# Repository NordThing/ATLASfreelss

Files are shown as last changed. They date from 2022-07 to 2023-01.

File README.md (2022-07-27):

# REWORK of ATLAS 3D scanner

ATLAS 3D scanner files - both for hardware and software and 3d printing files collected on one place.
Will make total rework of the ATLAS 3D scanner.

A link for assembling https://youtu.be/TEsBM5ACriQ 
and one more https://www.youtube.com/watch?v=awtLSCLJ3qs

Calibration video https://youtu.be/vvfXvUgtoUg

# FreeLSS

FreeLSS is a laser scanning program for the Raspberry Pi. It allows a Raspberry Pi to function as the core to a complete turn table laser scanning system.

### COMPILE

These instructions assume you are running the latest version of Raspbian.  Other distros will likely require changes.

First, update the firmware to the latest version and reboot.
```
$ sudo apt-get update
$ sudo apt-get upgrade
```

Install the dependencies that are managed by the package manager.
```
$ sudo apt-get install libpng-dev libjpeg-dev git-core gcc build-essential unzip sqlite3 libsqlite3-dev libmicrohttpd-dev libcurl4-openssl-dev libiw-dev libssl-dev wiringpi 
```

Download and build FreeLSS
```
$ git clone https://github.com/hairu/freelss
$ cd freelss
$ make
```
### Running FreeLSS
FreeLSS must be ran as root (or another user with access to the hardware pins).  The interface for FreeLSS is web based and by default runs on port 80.  When running, access it by navigating to http://localhost/ from the Raspberry Pi itself. Or access it from another machine on the network by the Raspberry Pi's IP or hostname.  For Example: http://raspberrypi/

The following command starts FreeLSS.
```
$ cd src
$ sudo ./freelss
```

The following command automatically starts FreeLSS everytime the Raspberry Pi is powered on.
```
$ make startup
```

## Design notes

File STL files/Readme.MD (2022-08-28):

# STL files for 3d printing

Printing times for the files here: 
1. Printing parts nr 1-5 for the camera - estimated time 49min, printing time 100mm/sec 30% infill 1h 25min 13 sec
   - camera_arm
   - camera_bracket
   - camera_case_back
   - camera_case_front
   - camera_shaft
2. Printing part nr 6 - frame_connector x 6 - estimated time 2h 29 min, printing time 100mm/sec 30% infill 4h 8min 19sec
3. Printing part nr 7 - frame_section_2 x 2 - estimated time 1h 31min, printing time 100mm/sec 30% infill 2h 21min 36sec
4. Printing parts 8-9 - estimated time 1h 45 min, printing time 100mm/sec 30% infill 2h 54min 42sec
   - left_laser_arm
   - right_laser_arm 
5. Printing parts 10-11 - estimated time xh xxmin, printing time 100mm/sec 30% infill xh xxmin xxsec
   - left_frame_section_3
   - right_frame_section_3
6. Printing parts 12-14 - estimated time 1h 20min, printing time 100mm/sec 30% infill 2h 13min 10sec
   - left_laser_holder
   - right_laser_holder
   - rpi_cable_carrier x 4
   - cross_bar x 5
7. Printing parts 16-17
   - camera_tower
   - camera_tower_front_plate
9.    

# STL files for 3d printing - probably a better print order

1. Printing the frame_connector x 6 
2. Printing the frame_section_2 x 4
3. Printing cross_bar x5
4. Print the right raspberry pi case for your purpose
5. Print the camera_tower 

Summary
These are the printable models for the ATLAS 3D turntable laser scanner by Murobo. ATLAS 3D is a turntable 3D laser scanner based on the Raspberry Pi. It runs the open source FreeLSS http://www.freelss.org laser scanning software available on Github https://github.com/hairu/freelss/. ATLAS 3D is a successful Kickstarter that is now available to the public.

The following models are required to build ATLAS 3D:

1. camera_arm.stl, x 1
2. camera_bracket.stl, x 1
3. camera_case_back.stl, x 1
4. camera_case_front.stl, x 1
5. camera_shaft.stl, x 1
6. frame_connector.stl, x 6
7. frame_section_2.stl, x 4
8. left_laser_arm.stl, x 1
9. right_laser_arm.stl, x 1
10. left_frame_section 3.stl, x 1
11. right_frame_section 3.stl, x 1
12. left_laser_holder.stl, x 1
13. right_laser_holder.stl, x 1
14. rpi_cable_carrier.stl, x 4
15. crossbar.stl, x 5
16. camera_tower.stl, x 1
17. camera_tower_front_plate.stl, x 1
18. table_coupler.stl, x 1
19. 
    - calibration_item.stl or 
    - checkerboard_calibration_item.stl, x 1
20. The calibrationPattern.pdf in the folder /calibration/ file needs to be printed and glued onto the checkerboard_calibration_item.stl model if you want to use the checkerboard auto-calibration.

Raspberry Pi 2 and Raspberry Pi 1 Model B+ users need to print the below two models.

1. rpi_case_bplus_lower.stl
2. rpi_case_bplus_upper.stl

Raspberry Pi 1 Model B users need to print the below two models.

1. rpi_case_b_lower.stl
2. rpi_case_b_upper.stl

Only one of the following turntables needs to be printed.

1. turn_table_d4.stl, 4" turntable
2. turn_table_d5p5.stl, 5.5" turntable
3. turn_table_d7p5.stl, 7.5" turntable

The following models are either optional or alternatives models.

1. camera_bracket_no_support.stl
2. left_camera_tower.stl
3. right_camera_tower.stl

The following models are only for the acrylic version of the enclosure.
1. left_laser_hinge.stl
2. left_laser_hinge_holder.stl
3. right_laser_hinge.stl
4. right_laser_hinge_holder.stl

Assembly Video: https://www.youtube.com/watch?v=awtLSCLJ3qs
Printable Instructions: http://www.soliforum.com/topic/13217/atlas-3d-scanner-instructions/

Another remix 
https://www.thingiverse.com/thing:754003

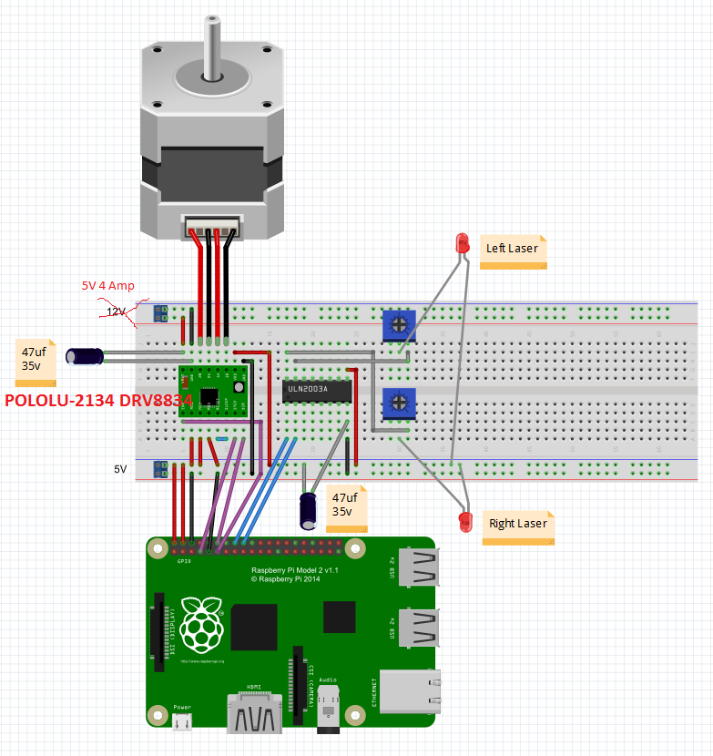
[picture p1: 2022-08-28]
electronic design/VDFLDOP.png

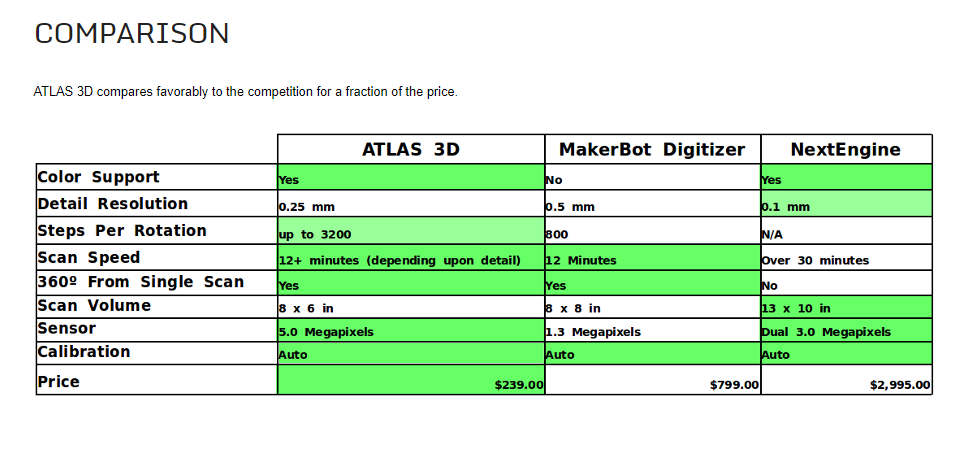
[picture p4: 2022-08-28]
comparison.PNG

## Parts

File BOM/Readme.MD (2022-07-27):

# Bill of materials

Board
1. 1 x Pololu A4988 stepper driver
2. 1 x ULN2003A
3. 2 x 47UF 35v low ESR
4. 2 x 10uf 5v capacitor
5. 2 x 100 ohm variable resistors

Electronic
1. 1 x Raspberry Pi 2
2. 1 x Power adapter for the Pi
3. 1 x Pi WiFi dongle
4. 1 x Official Pi camera 5Mp (version 1)
5. 2 x 3.3V line laser
6. 1 x Nema17 stepper motor

Hardware
1. 43 x M3x10mm flat head screws (Bag A)
2. 73 x M3 hex nuts (Bag B)
3. 34 x M3 washers (Bag C)
4. 31 x M3 14mm round head or socket cap screws (Bag D)
5. 4 x M2.5x10 flat head screws (Bag E)
6. 4 x M2.5 jam nuts (Bag F)
7. 4 x M3x20mm flat head screws (Bag G)
8. 4 x M2.5 washers (Bag H)

For the printed case's set of fasteners:
1. "Bag A" as referenced in the instructions is 43x M3x10mm screws.
2. "Bag B" is 73x M3 hex nuts
3. "Bag C" is 34 M3 washers
4. "Bag D" is 31 M3 socket cap screws
5. "Bag E" is 4x M2.5x10 screws
6. "Bag F" is 4x M2.5 jam nuts
7. "Bag G" is 4x M3x20mm screws
8. "Bag H" is 4x M2.5 washers

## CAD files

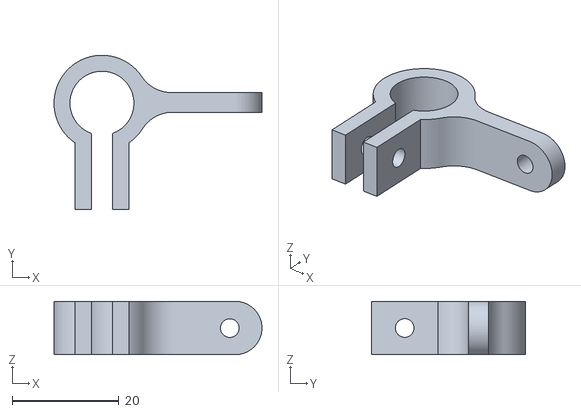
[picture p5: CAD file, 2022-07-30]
STL files/12mm_Laser_Holder_for_Atlas.stl
39.0 x 29.0 x 10.0

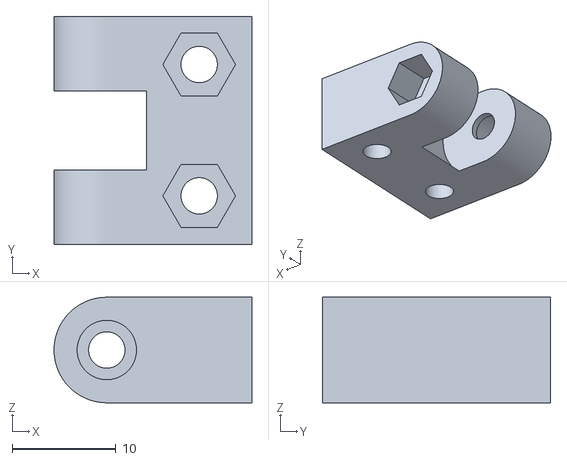
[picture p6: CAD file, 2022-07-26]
STL files/right_laser_hinge.stl
19.1 x 22.0 x 10.2

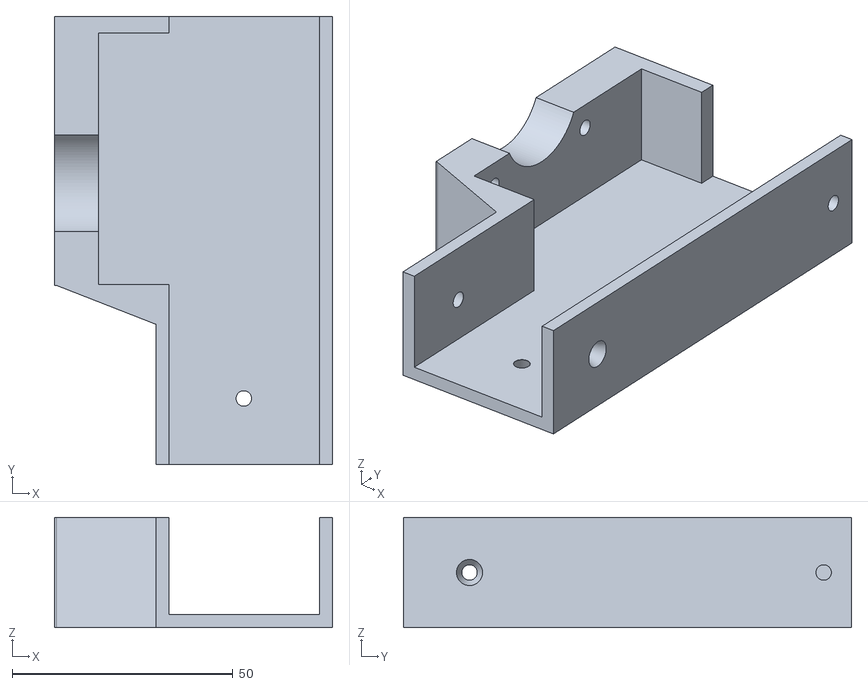
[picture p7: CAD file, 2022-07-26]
STL files/left_frame_section_3.stl
63.0 x 101.6 x 25.0

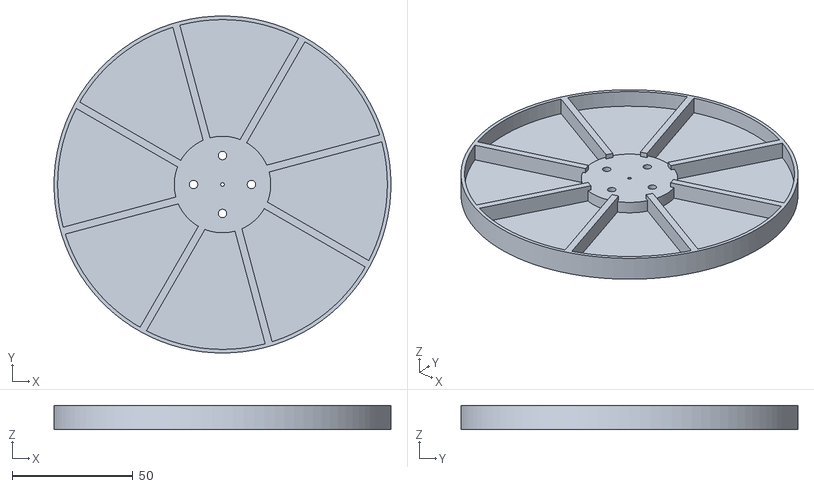
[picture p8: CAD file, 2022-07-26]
STL files/turn_table_d5p5.stl
139.7 x 139.7 x 10.0

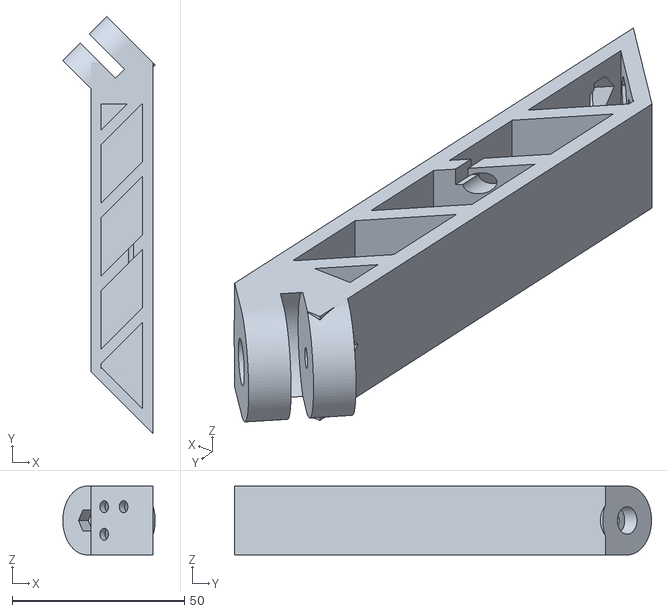
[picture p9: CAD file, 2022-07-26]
STL files/left_laser_arm.stl
26.9 x 121.2 x 20.0

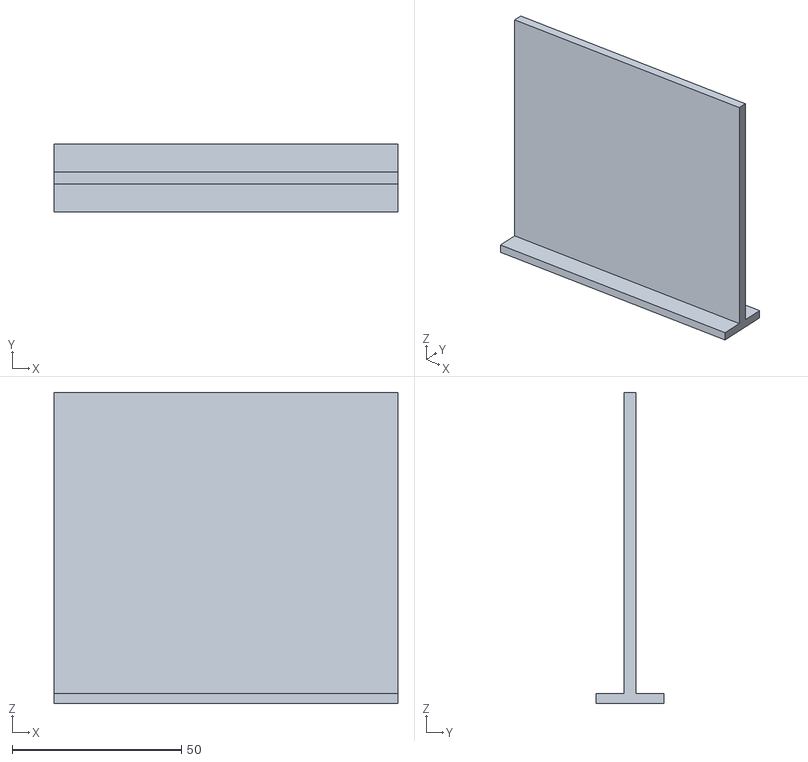
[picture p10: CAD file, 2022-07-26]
STL files/checkerboard_calibration_item.stl
101.6 x 20.0 x 91.9

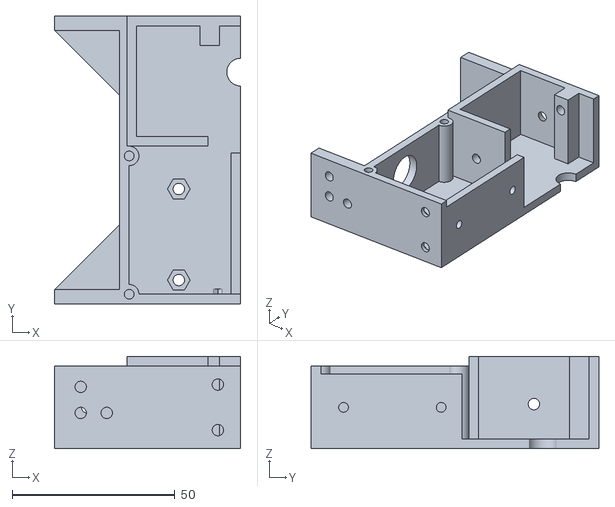
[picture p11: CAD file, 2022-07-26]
STL files/left_camera_tower.stl
57.2 x 88.5 x 28.4

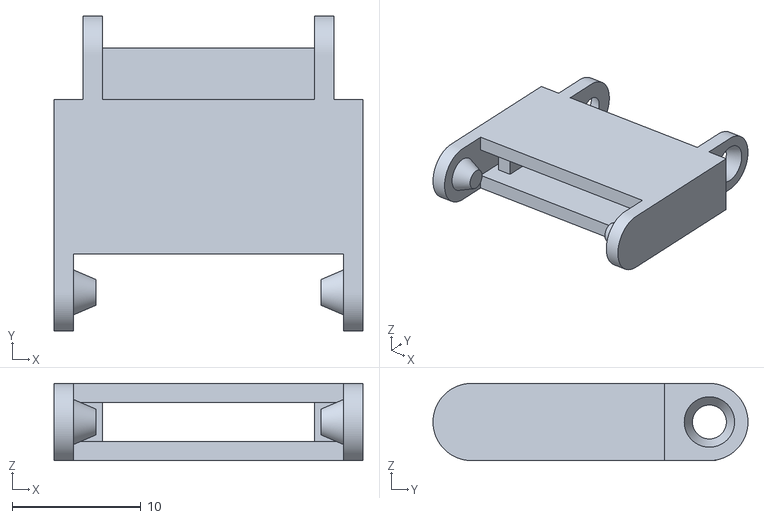
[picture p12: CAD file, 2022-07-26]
STL files/rpi_cable_carrier.stl
24.0 x 24.5 x 6.00

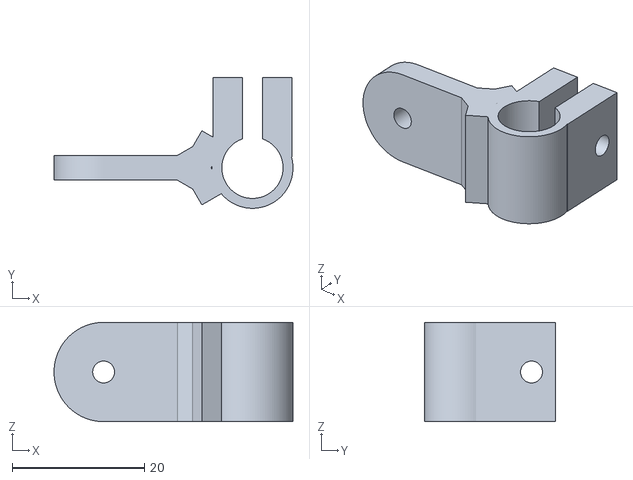
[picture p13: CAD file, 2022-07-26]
STL files/left_laser_holder.stl
36.1 x 19.8 x 15.0

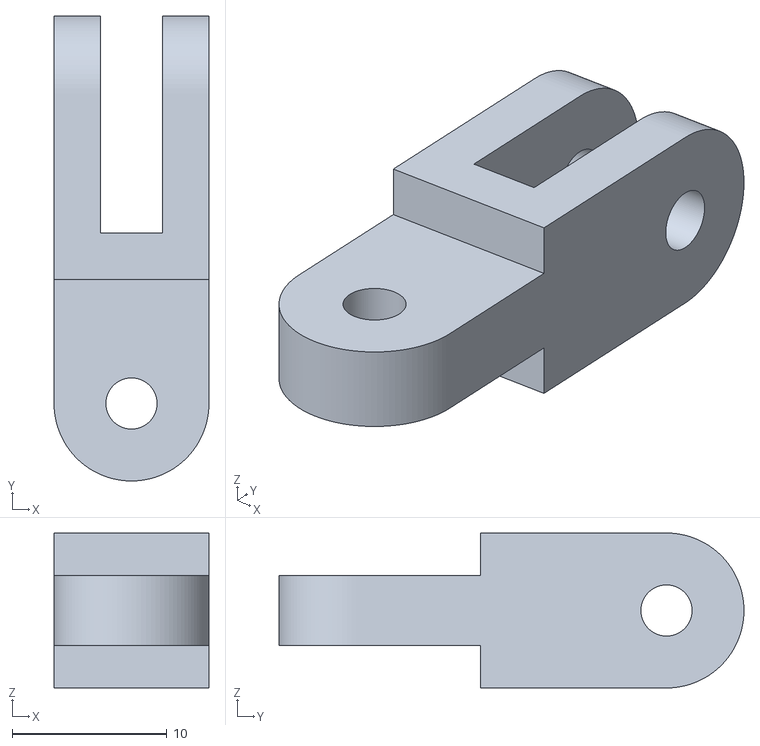
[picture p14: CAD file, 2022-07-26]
STL files/camera_bracket_no_support.stl
10.0 x 30.0 x 10.0

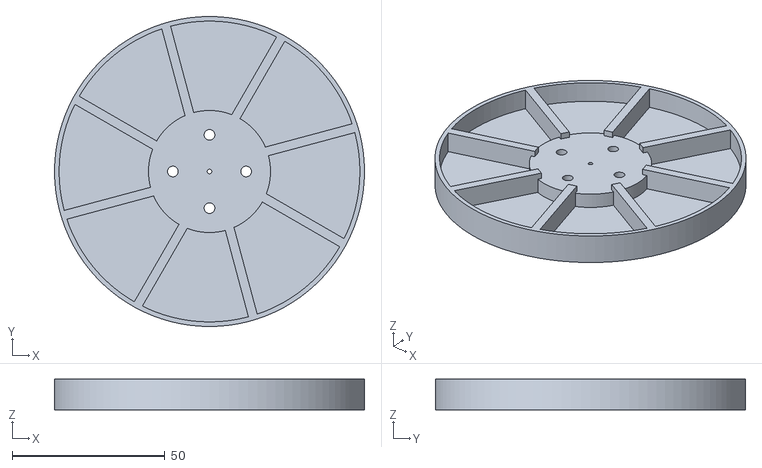
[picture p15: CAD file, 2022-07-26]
STL files/turn_table_d4.stl
101.6 x 101.6 x 10.0

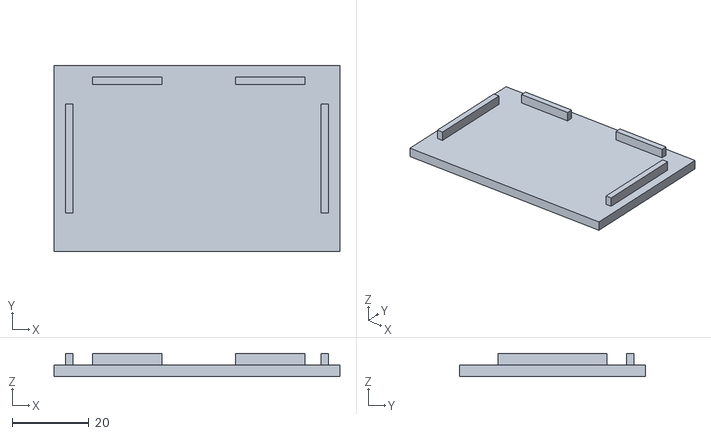
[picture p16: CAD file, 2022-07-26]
STL files/camera_tower_front_plate.stl
74.5 x 48.5 x 6.00

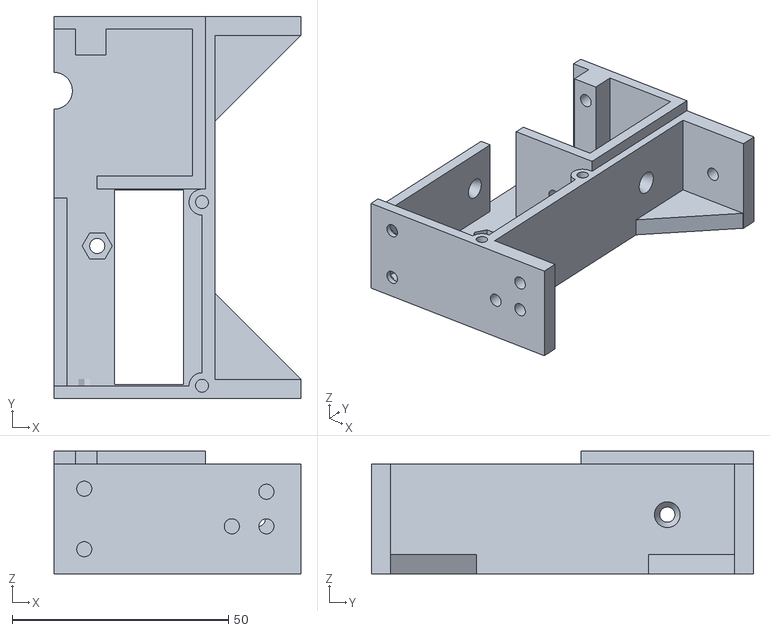
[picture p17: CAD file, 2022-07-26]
STL files/right_camera_tower.stl
57.1 x 88.5 x 28.4

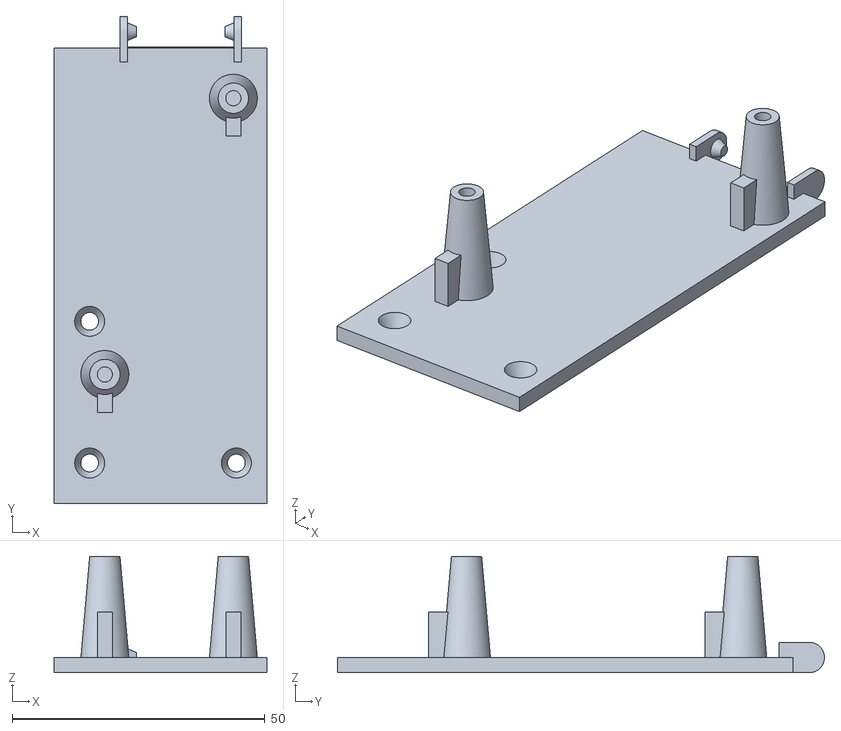
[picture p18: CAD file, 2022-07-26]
STL files/rpi_case_b_upper.stl
42.0 x 96.2 x 23.0

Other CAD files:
STL files/right_laser_holder.stl
STL files/left_laser_hinge.stl
STL files/camera_bracket.stl
STL files/camera_tower.stl
STL files/calibration_item.stl
STL files/camera_arm.stl
STL files/camera_case_back.stl
STL files/camera_case_front.stl
STL files/camera_shaft.stl
STL files/cross_bar.stl
STL files/frame_connector.stl
STL files/frame_section_2.stl
STL files/left_laser_hinge_holder.stl
STL files/right_frame_section_3.stl
STL files/right_laser_arm.stl
STL files/right_laser_hinge_holder.stl
STL files/rpi_case_b_lower.stl
STL files/rpi_case_bplus_lower.stl
STL files/rpi_case_bplus_upper.stl
STL files/table_coupler.stl
STL files/turn_table_d7p5.stl

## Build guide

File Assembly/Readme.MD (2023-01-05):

How to assemble the parts!

Where to start? 

Mount the FRAME
1. Mount all M3 nuts into all connectors first frame_connector.stl, each connector should have 6pcs M3 Nuts
2. Takae the frame-connector and connect to frame_section_2.stl with M3x10 mm screws. Screw in all three holes. 
3. The the next frame_section_2.stl and use with M3x10 screws. Screw in all three holes. 
4. Thake a new frame_connector.stl, eac connector should have 6 pcs m3 nuts. 
5. Attach the new frame_connector.stl with the frame_section_2 that is already there. 
6. Take left_frame_section_3.stl and connect it to the the new frame_section_2.stl with M3x10 in three screw holes. 
7. Attach a new frame_connector.stl on the opposite side. 
8. REPEAT EXACTLY THIS ONE MORE TIME - and you will have to identical sides 

Mount the Two frames together
1. Take cross_bar.stl and mount to one side with a M3 nuts and M3x10 screw 
2. Mount all 4x cross_bar.stl with M3 and M3x10 screws. 

Mount the motor
1. Take the motor and place it in the big hole with the axle at the center hole. 
2. Screw it with 4 screws - which size and with bricks. 

Mount the sides

Mount the camera-pole
1. Use the B nuts, c strings and D screws 
2. This is also questionable if we should use other screws for this part - i think the M3x10 screws will work for this part also. 

Mount the tower for laser 
1. Use the B nuts, c strings and D-screws. 
2. This is a real hazzle to mount the tower for the laser... needs improvement. 

Mount the laser-holder 
1. Put the mount for the laser-holder on the tower both left and right

Mount the camera holder on the camera-tower
1. camera_bracket.stl
2. camera_arm.stl

Mount the camera on the camera-arm 
1. 

1. Mount the Laser-pointer to the right mount. 12mm_Laser_Holder_for_Atlas.stl
2.

Mount the frame - 
Letter B - Hex M3 nuts 
Letter A - M3 x 10 mm

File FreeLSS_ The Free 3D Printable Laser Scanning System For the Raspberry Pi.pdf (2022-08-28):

## The Free 3D Printable Laser Scanning System

Get a Scanner Kit! (https://web.archive.org/web/20220226222454/https://www.kickstarter.com/projects/1545315380/atlas-3d-the-3d-scanner-you-print-and-build-yourse)

Get an ATLAS 3D scanner kit based on the FreeLSS software from the Murobo store. (https://web.archive.org/web/20220226222454/http://store.murobo.com/)

## About FreeLSS

FreeLSS is a free as in open source, open hardware, and open electronic design 3D printable turn table laser scanning platform based on the Raspberry Pi. (https://web.archive.org/web/20220226222454/http://www.raspberrypi.org/) It is written in C++ and licensed under the GPL. The scanning software runs self-contained on the Raspberry Pi without the need for a connected computer via USB. The user interface is completely web based and is exposed via libmicrohttpd (https://web.archive.org/web/20220226222454/http://www.gnu.org/software/libmicrohttpd/) on the Pi. Laser sensing is performed

The Wayback Machine - https://web.archive.org/web/20220226222454/http://www.freelss.org/

via the official 5 MP Raspberry Pi camera. The camera can be operated in either video or still mode. Video
mode camera access is provided by the | Raspicam (https://web.archive.org/web/20220226222454/http://www.uco.es/investiga/grupos/ava/node/40) library. Reference designs for the electronics to control the
lasers and turn table are available as | Fritzing (https://web.archive.org/web/20220226222454/http://fritzing.org/home/) files. Access to the GPIO pins are provided by | wiringPi. (https://web.archive.org/web/20220226222454/http://wiringpi.com/)

## Features

Fully 3D Printable
Point cloud export
Triangle mesh export
Assisted calibration
Support for dual laser lines (right and left)
Up to 6400 samples per table revolution (with reference electronics) 5 megapixel camera sensor
Support for camera Still mode and Video code
Configurable Image Processing Settings
Ability to generate images at different stages of the image processing pipeline for debugging Persistant storage of previous scans
Manual control of lasers and turn table
Flexible architecture

## Formats

FreeLSS can generate results in the following formats. PLY - Colored Point Cloud
XYZ - Comma Delimited 3D Point Cloud
STL - 3D Triangle Mesh

## Download

Download the source on | Github. (https://web.archive.org/web/20220226222454/http://github.com/hairu/freelss)
Download the printable hardware files from | Thingiverse. (https://web.archive.org/web/20220226222454/http://www.thingiverse.com/thing:1280901)
Electronic design files: | Perfboard, (https://web.archive.org/web/20220226222454/https://s3.amazonaws.com/freelss/bb.png) | PCB (https://web.archive.org/web/20220226222454/https://s3.amazonaws.com/freelss/pcb.png)

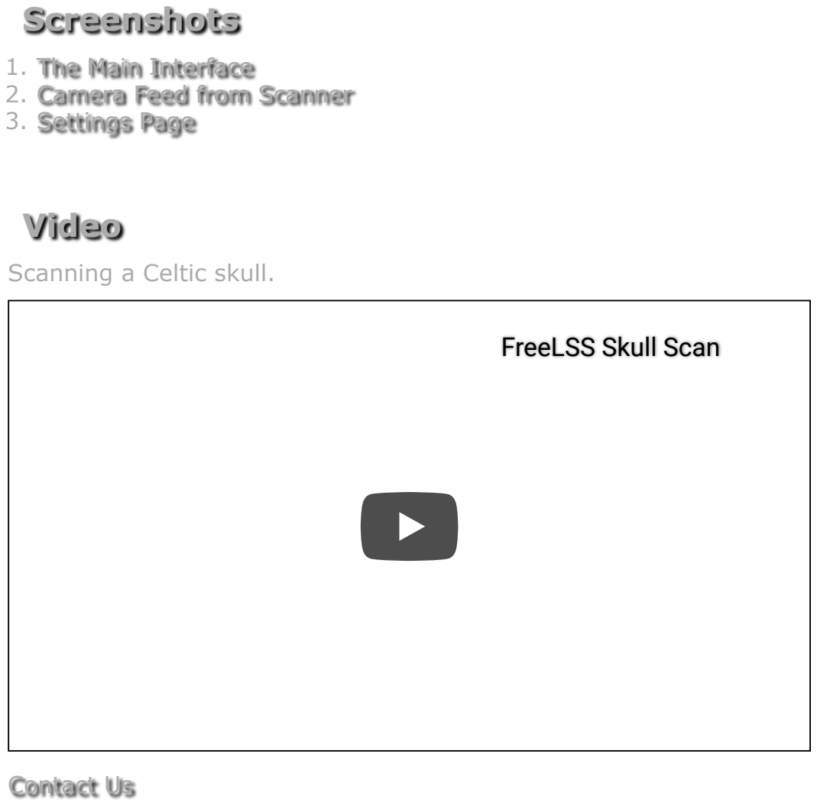
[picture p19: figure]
Screenshots; 1. The Main Interface 2. Camera Feed from Scanner 3. Settings Page; Video; Scanning a Celtic skull.; FreeLSS Skull Scan; Contact Us

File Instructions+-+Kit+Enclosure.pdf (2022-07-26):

## ATLAS 3D INSTRUCTIONS

### WARNING: The included components can be damaged by static electricity. Before touching or removing them from their bags you must ground yourself by touching an

earthed object such as a water tap or radiator. Failure to ground yourself can result in the destruction of the electronic parts.

### WARNING: The M4 screws must be hand tightened, using a wrench or other tool may

crack the acrylic.

### CAUTION: LASER RADIATION – DO NOT STARE INTO BEAM OR VIEW WITH

OPTICAL INSTRUMENTS.

### A video assembly guide is located at http://www.murobo.com/start.html#assembly

### See the Getting Started page at http://www.murobo.com/start.html

The product serial number is located at the bottom of the motor. This serial number is required for certain ATLAS 3D features.

## KIT ENCLOSURE ASSEMBLY INSTRUCTIONS

See the assembly video for a visual guide.

1. Check and ensure that you have all of the pieces on your paper and then begin peeling off the tape on both sides of all acrylic pieces.
2. Put the SD card into the SD slot of the Raspberry Pi.
3. Attach the 40 pin side of the bribbon cable to the Raspberry Pi ensuring that the white stripe is closest to the SD card.
4. Connect the included extension camera cable to the Raspberry Pi. Pull up on the plastic camera connector bar to open it and push down to close it. The metal contacts on the cable must be pointing away from the USB slots (towards the SD card).
5. Pull the other end of the camera cable out of the small rectangle cut above the Raspberry Pi on the FD piece.
6. Lay FB flat as illustrated. Slide FC into the groves of FB (make sure that the rectangle cutout is on the left hand side when looking from the motor) and then connect FC to FB using 3 of the M4 screws and nuts in bag A. Hold the nut in place with your fingers and screw in the fastener. Leave the screws a little loose for easier assembly.
7. Slide FD into the groves of FB (be sure that the small LED indication circle is at the bottom left hand side when facing the camera from the motor) and then put in the M4 fasteners from bag A but do not tighten yet.
8. Grab the 4 M2.5 18mm screws from bag H and put them into the 3 holes (by the rectangle) of the FC acrylic starting from the bottom. Place the FT spacers over the 4 mounting holes and sit the Raspberry Pi onto the three screws followed by the M2.5 nuts found in the H bag.
9. Pull the ribbon cable down through the hole in FC.
10. Using the M3 screws found in bag B, the nuts found in bag E, and 3 FU spacers, attach the electronics board to FJ running the screws up from the bottom. Ensure that the power plug lines up with the hole on the FD piece. If it does not then disconnect the electronics board from FJ, flip FJ and then reconnect the electronics board.
11. Once you connect the electronics board to FJ you can then attach the 2 rubber feet using the screws from bag B and the nuts from bag E.
12. Using the screws from bag B and the nuts from bag E attach the 2 remaining rubber feet to FI and sit aside.

### Page 1 of 7

13. Unscrew the plastic cap on the button if not already unattached. Put the head of the button into the FV hard board. Screw the plastic cap back onto the button.
14. Attach the button into the side of FB using the screws from bag B and the nuts from bag E. Be sure to have the button on the inside of the frame.
15. Connect the button’s cords to the electronics board where it says power.
16. Pull the laser cords through the same hole as the camera cable and then down the rectangular hole on the FC piece. Connect the laser wires to the electronics board where indicated on the electronics board. The wires should go red, black, red, black (see figure below).
17. Connect the motor wires to the electronics board in the following order: green, black, red, blue (see figure below).
18. Attach the motor to the FC section of the frame using M3 10mm screws found in bag G.
19. Connect the 26pin side of the black ribbon cable to the electronics board. Ensure that the white portion of the ribbon cable is pointed toward the motor. An incorrect connection of the ribbon cable may result in damage to the Pi, board, or both.
20. Pull FD out a little and sit FJ into the slots of FB and then push FD back into place.
21. Put FK into the slots of FB sitting above the Raspberry Pi. Put FH into the slots of FB at the back of the Pi. Put FI into the slot of FB in front of the motor with the feet facing down. Put FG in the front slot of FB in front of the motor.
22. Attach FA to the assembly ensuring that all of your slots fit into place. Put in 6 fasteners and nuts from the A bag. Hand tighten these fasteners.
23. Put in the last fastener on FB and hand tighten that one and the two connecting FD to FB.
24. Take FE and put it in front of FF and connect the horizontal holes of FE to the two end holes on FF using the screws from bag B and the nuts from bag E. Tighten using the wrench.
25. Put the laser arm into the laser holder and fasten down using the screws from bag B and the nuts from bag
E. Do this to both laser holders, left and right.
26. Connect FF to FD using the screw from bag B. Only use 1 and you will put this screw in the first slot next to FE. Do this on both sides.
27. Connect the laser holders to FE using the screws from bag B and the nuts from bag E.
28. Insert the laser into the holder and put the screw from bag B and nut from bag E through the bottom of the holder to keep the laser in place.
29. Remove the default cable that is connected to the camera by pulling up on the plastic bar where the cable meets the camera.
30. Connect the longer cable, that was previously attached to the Pi, to the camera by inserting it into the slot and pushing down on the bar. The metal contacts must be facing the same direction as the camera lens.
31. Use the nylon screws in bag C and put them in the camera holes on FD. Attach the springs onto the screws followed by the nylon washer. Attach the camera onto the screws. (the camera cable will be coming up and then flip downward towards the Pi) Put the nylon nut on the screw and semi tighten.
32. Lay the wooden table down on top of the table liner and cut to the table size. Lay FP onto the table matching up the pilot holes. Put the nuts from bag E into the 4 slots in FP. Align FQ on top of FP. Attach FQ and FP to the table using the wood pointed tip screws in bag F. Be careful not to over tighten or you will strip the wood (see diagram below).
33. Lay FO on top of FQ. Lay the M2.5 screw and nut from bag F onto the side slot in FO. Align the 3D printed FN on top of FO and use the M3 18mm screws from bag F to connect FN to FP.
34. Sit the table onto the motor. Turn the table to see if it is turning level. If not then adjust the table on the motor until you get it turning level. Once you get the table turning level then tighten the small M2.5 screw in FO to affix the table to the motor shaft. It is important to make sure that the table is turning level before proceeding.
35. Stack the 3 FM pieces together and affix to the hard wood calibration item (FW) using the M3 25mm screws found in bag D and the nuts found in bag E.
36. The serial number is located on the bottom of the motor. You will need to enter your serial number and update your software.
37. To calibrate your camera you will need to tighten or loosen the nylon screws holding the camera.
38. Once your camera and lasers are calibrated use the screws from bag D and put them through the holes on

### Page 2 of 7

FD that are next to the camera. Put a FU spacer onto the screw. Put the remaining 2 screws in bag D into the lower 2 of the remaining holes on FD. Put 2 FU spacers on each of those two screws. Pull in the laser wires and then attach FL onto the 4 screws using the nuts from bag E (see diagram below).
39. Put your table liner on top of your wooden table. Your ATLAS 3D kit is now assembled.

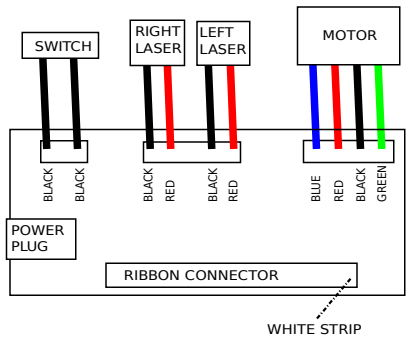
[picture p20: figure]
SWITCH; POWER PLUG; LEFT; MOTOR; LASER; RIGHT LASER; GREEN; BLACK; RED; BLUE; RIBBON CONNECTOR; WHITE STRIP

### Page 3 of 7

FN

FO

FP
FQ

M3 Screws
to M3 Nut

Turntable

M2.5 Nut & Screw

Wood Screw | Wood Screw

Pi
M2.5 Nylon Washer

FT

M2.5 Screw

M2.5 Nut

FC

### Turntable Assembly

Pi Assembly | Camera Assembly
FD | Nylon M2 Screw

M2 Nylon Washer

Spring
Nylon M2 Nut

Camera Board

### Electronics Board Wiring

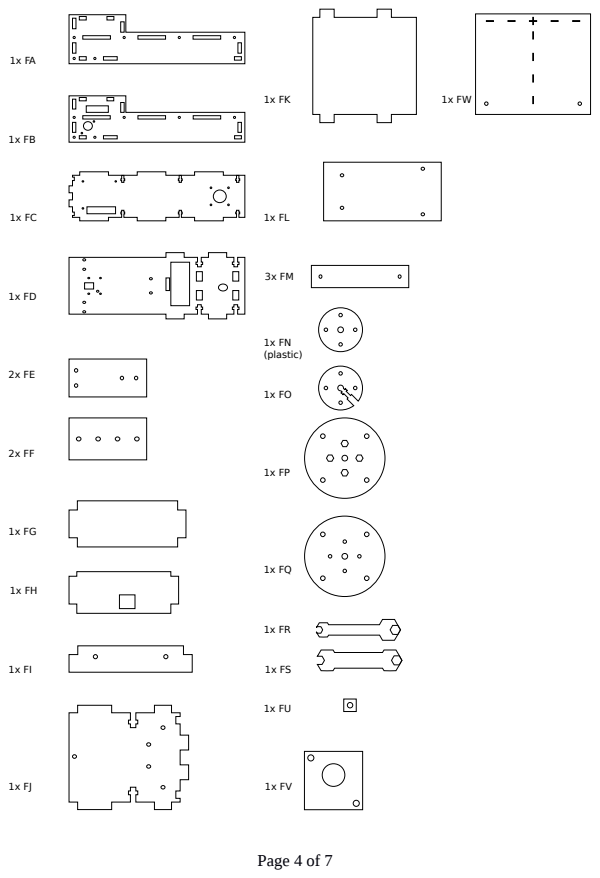
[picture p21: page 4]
Page 4 of 7; 1x FN (plastic)

## WiFi Setup and Connecting to the Scanner

To recommended way of establishing an initial connection to the scanner is to use a USB flash drive to assist in the setup and connection. The instructions below describe this process.

## Microsoft Windows

1. Insert the WiFi dongle into the Raspberry Pi
2. Insert a USB flash drive into the Raspberry Pi (wait for the lasers to turn on and turn back off).
3. Insert the flash drive into your PC and run the program called ATLAS3D_Windows.hta that was written to the flash drive.

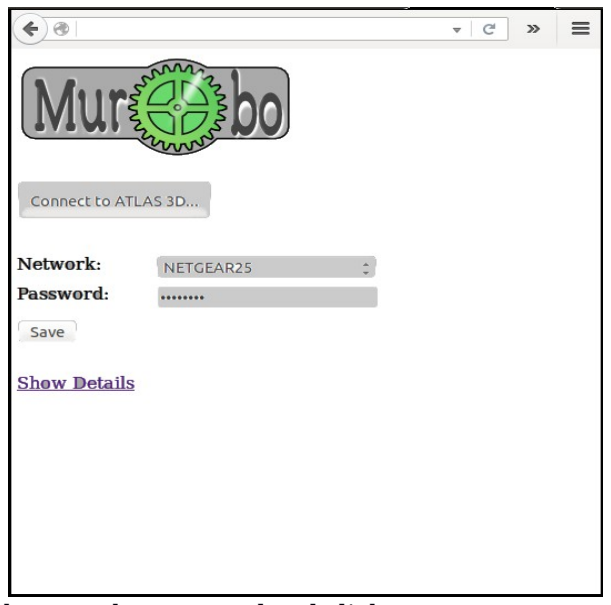
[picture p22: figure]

4. Select your WiFi network, enter the password and click save.
5. Insert the USB flash drive back into the Pi (wait for lasers to turn on and turn back off)
6. Insert the USB flash drive back into your computer, run the ATLAS3D_Windows.hta program and click Connect to ATLAS 3D.

Once connected, following the getting started guide at http://www.murobo.com/start.html

## Mac and Linux

1. Insert the WiFi dongle into the Raspberry Pi
2. Insert a USB flash drive into the Raspberry Pi (wait for the lasers to turn on and turn back off).
3. Edit the file named ATLAS3D_cfg.txt and enter your WiFi network and password on the cooresponding lines.

### Page 5 of 7

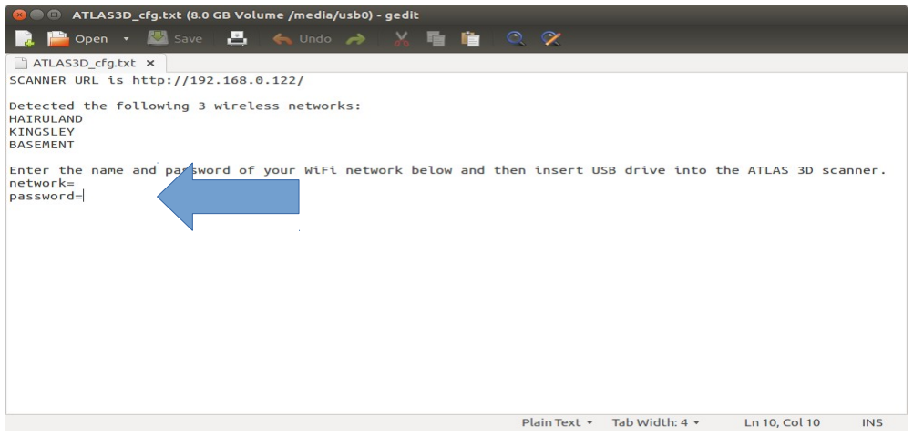
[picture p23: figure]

4. Save the file, insert it into the Raspberry Pi and wait for the lasers to turn on and off again.
5. Insert the USB flash drive back into your computer, double-click the ATLAS3D_Connect.html file and click Connect to ATLAS 3D.

Once connected, following the getting started guide at http://www.murobo.com/start.html

## No USB Flash Drive

It is strongly recommended to use a USB flash drive, but if one is not available, you can connect with the following instructions.
1. Attach an HDMI monitor, USB keyboard, and USB mouse to the Raspberry Pi.
2. Power on the scanner and login with pi as the username and raspberry as the password.
3. Type startx and press the Enter key to start the GUI.
4. Click the globe icon at the top left of the GUI to screen to start the web browser.
5. Enter http://127.0.0.1/ into the location bar and press the Enter key to access the ATLAS 3D software.
6. Click SETTINGS and then Network to access the network setup page.
7. Select your WiFi network, enter your password, and press Connect.
8. Wait 30 seconds for the scanner to connect to WiFi and click the Network page again to refresh

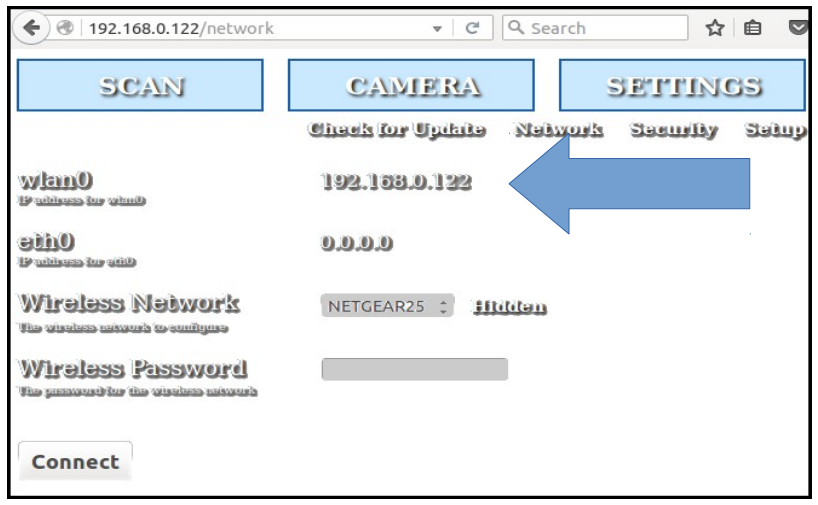
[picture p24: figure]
Page 6 of 7

the page.
9. The number to the right of wlan0 is the WiFi IP address for the scanner.
10. From your desktop PC, open Firefox, Chrome, Safari or any modern web browser and enter http://IP_ADDRESS/ into the location bar, where IP_ADDRESS is your WiFi IP address. For example, in the example above it would be http://192.168.0.122/

Once connected, following the getting started guide at http://www.murobo.com/start.html

## Command Line Only – Advanced Users Only

1. Attach an HDMI monitor, USB keyboard, and USB mouse to the Raspberry Pi (alternatively, you can attach via Ethernet, discover the IP address and shell in with SSH).
2. Power on the scanner and login with pi as the username and raspberry as the password.
3. Type sudo nano /etc/wpa_supplicant/wpa_supplicant.conf to edit the WiFi configuration file.
4. Enter the network name on the ssid line and password on the psk line. Note that the double quote “ characters before and after the password and network are required.

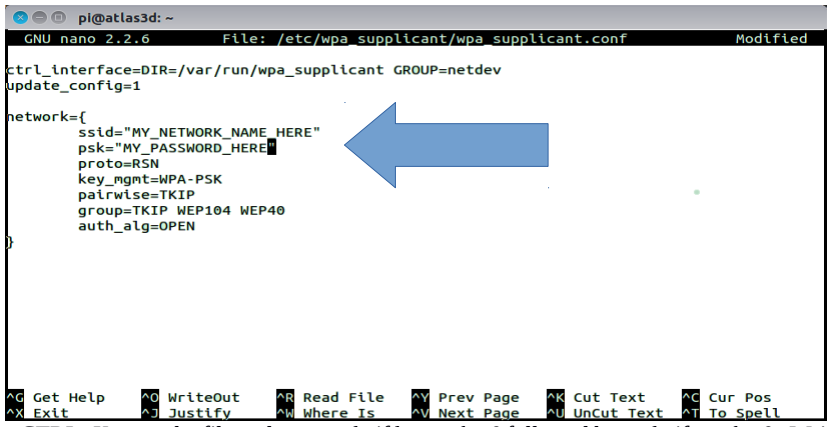
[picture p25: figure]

5. Press CTRL+X, save the file and type sudo ifdown wlan0 followed by sudo ifup wlan0. Wait 30 seconds and type ifconfig to see if wlan0 has an IP address.
6. From your desktop PC, open Firefox, Chrome, Safari or any modern web browser and enter http://IP_ADDRESS/ into the location bar, where IP_ADDRESS is your WiFi IP address. For example, in the example above it would be http://192.168.0.122/

Once connected, following the getting started guide at http://www.murobo.com/start.html

### Page 7 of 7

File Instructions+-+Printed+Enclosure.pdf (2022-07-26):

## ATLAS 3D Instructions

### WARNING: The included components can be damaged by static electricity. Before touching or removing them from their bags you must ground yourself by touching a earthed object such as a water tap or radiator. Failure to ground yourself can

result in the destruction of the electronic parts.

## CAUTION: LASER RADIATION – DO NOT STARE INTO BEAM OR

VIEW WITH OPTICAL INSTRUMENTS.

See the Getting Started page at http://www.murobo.com/start.html

Links to the 3D printed parts can be found at http://www.murobo.com/printables.html

The product serial number is located at the bottom of the motor.

## Assembly Instructions

A step-by-step video of the assembly can be found at https://www.youtube.com/watch?v=awtLSCLJ3qs (https://www.youtube.com/watch?v=awtLSCLJ3qs)

1. Print the 3D printable parts.
2. Use a frame connector to connect two frame section 2 parts with A-screws and B-nuts.
3. Add a frame connector to the end of a frame section 2.
4. Use another frame connector to connect the frame section 3 to the opposite end of the frame.
5. Follow the above instructions to assemble the other side of the frame.
6. Attach four cross bar parts to the center of one the frame section 2 parts for one side of the frame.
7. Attach the motor to frame section 3 using D-screws and C-washers.
8. Place tape over the nuts of the cross bar to prevent them from falling out.
9. Use the cross bars to join the two frame sides with A-screws.
10. Use D-scews and C-washers to attach the other side of the frame to the motor.
11. Attach the power button onto the electronics board by pushing down on the top button and inserting the wires into the side.
12. Attach the top Raspberry Pi case to the camera tower with A-screws and B-nuts.
13. NOTE: Remember to cut and remove the printed support structure between the cable carrier of the upper Raspberry Pi case.
14. Feed the laser wires through the side holes on the Raspberry Pi case and through the rectangular cutout in the camera tower.
15. Attach the lasers to the electronics board. The order of the wires from back to front (where the barrel plug is) is left laser red, left laser black, right laser red, right laser black. This is also written on the PCB.
16. Attach the electronics board to the camera tower with a D-screw, two C-washers and a B nut.
17. Unscrew the fastener for the power button and insert the power button into the power cutout in the camera tower. Screw the fastener back on to hold the power button in place.
18. Connect the motor to the electronics board. The back to front order is green, black, red, and then blue.
19. Connect the ribbon cable to the electronics board. Ensure that the white strip faces towards the back of the board.

## ATLAS 3D Instructions

20. Insert nuts into the unconnected frame connectors and place taper over them to prevent them from falling out.
21. Join the camera tower to the frame with A-screws on the bottom and sides, and D-screws and C-washers on the top.
22. Attach the camera shaft to the camera tower with D-screws, C-washers and B-nuts.
23. Attach both laser arms with D-screws, C-washers, and B-nuts.
24. Place nuts in the remaining cross bar and use it to attach the back feet to the scanner. Use a D-screw, C-washer, and B-nut for each foot.
25. Use a D-screw, two C-washers, and a B-nut for the front side feet (the side closest to the camera).
26. Attach the laser holders to the laser arm using a D-screw, C-washer and B-nut.
27. Insert the lasers into the laser holder. Use a D-screw, C-washer, and B-nut to hold the laser in place.
28. Attach the Raspberry Pi to the bottom Raspberry Pi case with E-screws, F-nuts, and H-washers. Tweezers can help to hold the nuts in place.
29. Insert the SD card into the Raspberry Pi with the metal contacts pointing up.
30. Attach the camera bracket to the camera arm using D-screws, C-washers, and B-nuts.
31. Attach the front camera case using D-screws, C-washsers, and B-nuts.
32. Attach the camera bracket, camera arm, and front camera case to the camera shaft.
33. Connect the four cable carriers by snapping them together.
34. Snap on the cable carrier to the upper Raspberry Pi case.
35. Insert the camera into the front camera case.
36. Feed the camera cable through the cable carrier.
37. Connect the cable carrier to the front camera case.
38. Snap on the back camera case.
39. Connect the camera cable to the Raspberry Pi. Open the CSI connector by pulling up on it. Insert the camera cable with the metal contacts pointing down and push down on the CSI connector to close it. Ensure that the cable sits evenly in the connector.
40. Connect the ribbon cable to the Raspberry Pi with the white strip pointing down.
41. Snap the lower Raspberry Pi case to the upper Raspberry Pi case.
42. Attach the camera tower front plate.
43. Insert the Wifi dongle.
44. Tighten all of the screws of the frame.
45. Place the turntable upside down onto the table liner and run a sharp knife around the table to create a circular cutout. Be careful not to cut yourself.
46. Insert four B-nuts into the bottom of the table coupler. Use tape to hold them in place.
47. Place the coupler on the motor shaft with the big end pointing up.
48. Insert two B-nuts into the top of the table coupler and two D-screws into the sides to hold the coupler onto the motor shaft.
49. Snap the turntable onto the table coupler.
50. Use G-screws to attach the table to the coupler.
51. Place the table liner onto the turntable.

## WiFi Setup and Connecting to the Scanner

To recommended way of establishing an initial connection to the scanner is to use a USB flash drive to assist in the setup and connection. The instructions below describe this process.

### Microsoft Windows

## ATLAS 3D Instructions

1. Insert the WiFi dongle into the Raspberry Pi
2. Insert a USB flash drive into the Raspberry Pi (wait for the lasers to turn on and turn back off).
3. Insert the flash drive into your PC and run the program called ATLAS3D_Windows.hta that was written to the flash drive.

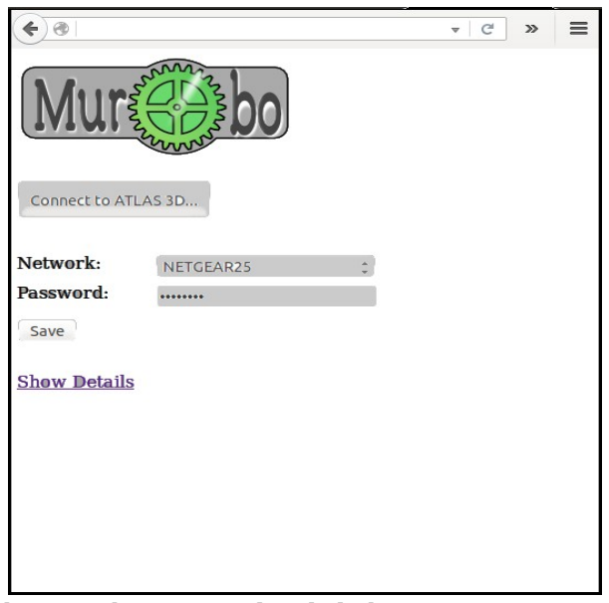
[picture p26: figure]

4. Select your WiFi network, enter the password and click save.
5. Insert the USB flash drive back into the Pi (wait for lasers to turn on and turn back off)
6. Insert the USB flash drive back into your computer, run the ATLAS3D_Windows.hta program and click Connect to ATLAS 3D.

Once connected, following the getting started guide at http://www.murobo.com/start.html

### Mac and Linux

1. Insert the WiFi dongle into the Raspberry Pi
2. Insert a USB flash drive into the Raspberry Pi (wait for the lasers to turn on and turn back off).
3. Edit the file named ATLAS3D_cfg.txt and enter your WiFi network and password on the cooresponding lines.

## ATLAS 3D Instructions

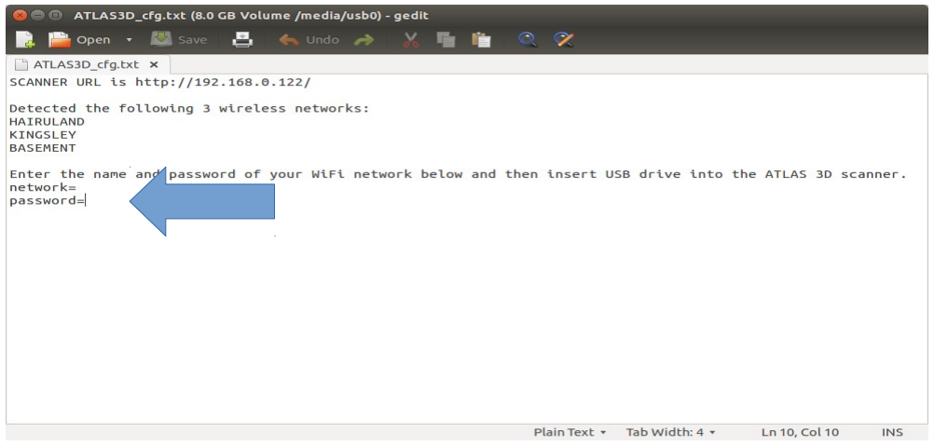
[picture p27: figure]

4. Save the file, insert it into the Raspberry Pi and wait for the lasers to turn on and off again.
5. Insert the USB flash drive back into your computer, double-click the ATLAS3D_Connect.html file and click Connect to ATLAS 3D.

Once connected, following the getting started guide at http://www.murobo.com/start.html

### No USB Flash Drive

It is strongly recommended to use a USB flash drive, but if one is not available, you can connect with the following instructions.
1. Attach an HDMI monitor, USB keyboard, and USB mouse to the Raspberry Pi.
2. Power on the scanner and login with pi as the username and raspberry as the password.
3. Type startx and press the Enter key to start the GUI.
4. Click the globe icon at the top left of the GUI to screen to start the web browser.
5. Enter http://127.0.0.1/ into the location bar and press the Enter key to access the ATLAS 3D software.
6. Click SETTINGS and then Network to access the network setup page.
7. Select your WiFi network, enter your password, and press Connect.
8. Wait 30 seconds for the scanner to connect to WiFi and click the Network page again to refresh the page.

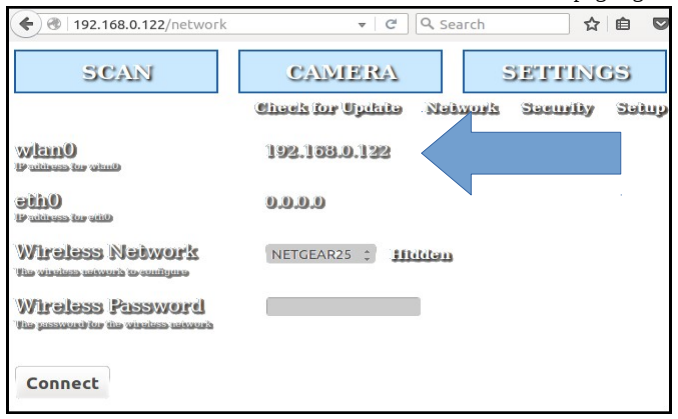
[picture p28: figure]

## ATLAS 3D Instructions

9. The number to the right of wlan0 is the WiFi IP address for the scanner.
10. From your desktop PC, open Firefox, Chrome, Safari or any modern web browser and enter http://IP_ADDRESS/ into the location bar, where IP_ADDRESS is your WiFi IP address. For example, in the example above it would be http://192.168.0.122/

Once connected, following the getting started guide at http://www.murobo.com/start.html

### Command Line Only – Advanced Users Only

1. Attach an HDMI monitor, USB keyboard, and USB mouse to the Raspberry Pi (alternatively, you can attach via Ethernet, discover the IP address and shell in with SSH).
2. Power on the scanner and login with pi as the username and raspberry as the password.
3. Type sudo nano /etc/wpa_supplicant/wpa_supplicant.conf to edit the WiFi configuration file.
4. Enter the network name on the ssid line and password on the psk line. Note that the double quote “ characters before and after the password and network are required.

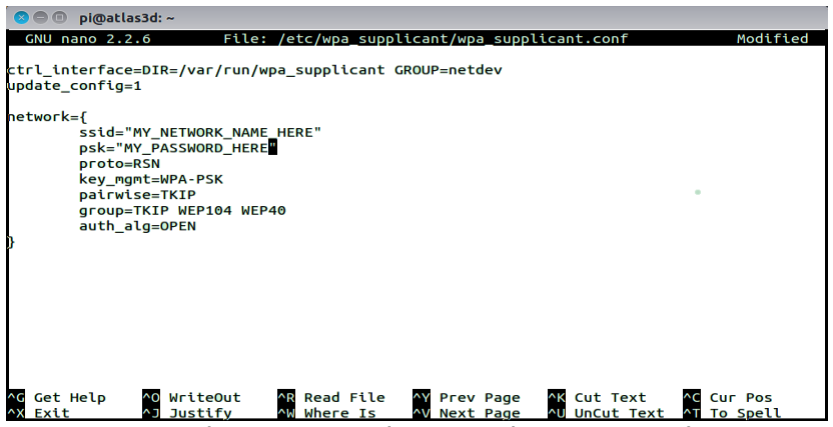
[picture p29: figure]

5. Press CTRL+X, save the file and type sudo ifdown wlan0 followed by sudo ifup wlan0. Wait 30 seconds and type ifconfig to see if wlan0 has an IP address.
6. From your desktop PC, open Firefox, Chrome, Safari or any modern web browser and enter http://IP_ADDRESS/ into the location bar, where IP_ADDRESS is your WiFi IP address. For example, in the example above it would be http://192.168.0.122/

Once connected, following the getting started guide at http://www.murobo.com/start.html

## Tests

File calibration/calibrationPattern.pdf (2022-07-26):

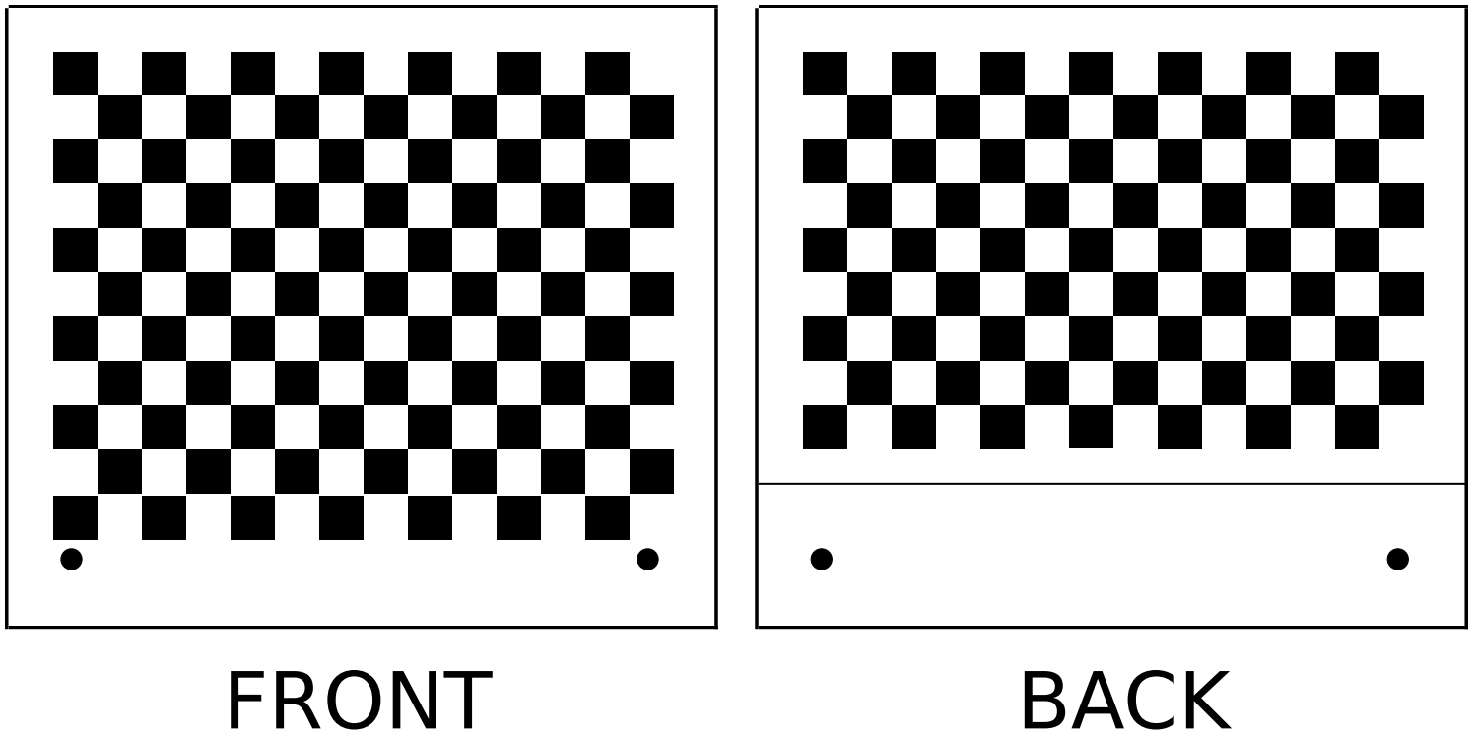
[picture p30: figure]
FRONT; BACK
